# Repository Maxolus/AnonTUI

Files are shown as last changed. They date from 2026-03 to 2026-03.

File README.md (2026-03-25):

# MoTUI: Personalization of In-Vehicle Tactile Interfaces for People With Vision Impairments and the Blind

<p align="center">
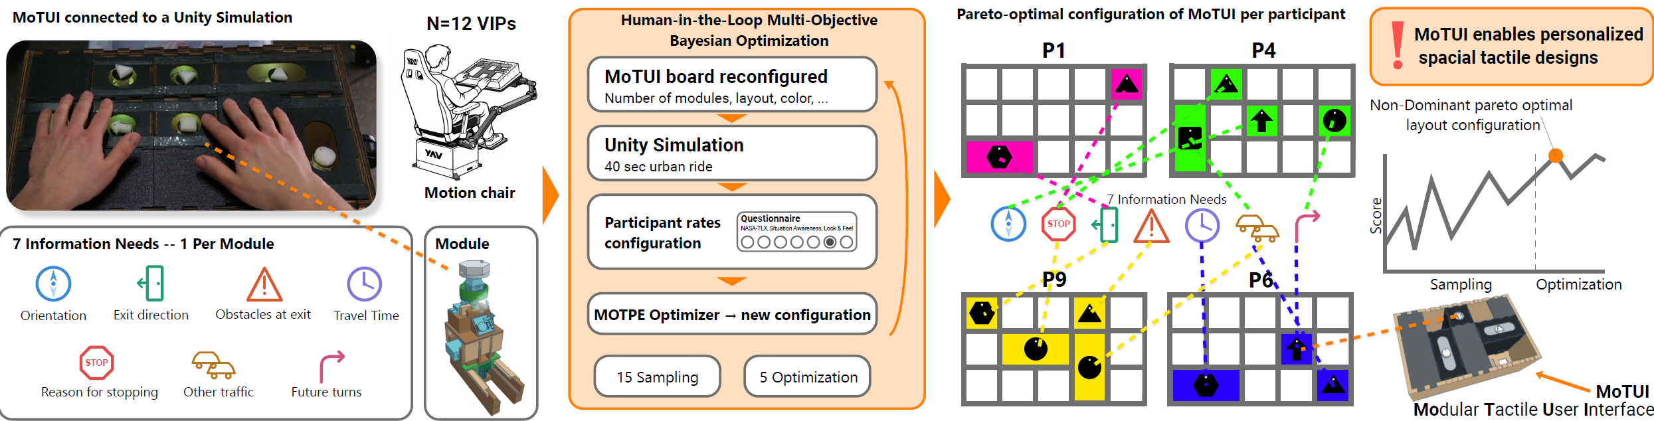
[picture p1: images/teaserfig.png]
MoTUI Teaser Figure
  
</p>

<p align="center">
  
  
  
  
  
  
  
  
  
</p>

---

## 📄 About

**MoTUI** is an open-source **Modular Tactile User Interface** that pairs reconfigurable hardware with **Human-in-the-Loop Multi-Objective Bayesian Optimization (HITL-MOBO)** to personalize in-vehicle interfaces for people with vision impairments (VIPs). Instead of one-size-fits-all designs, MoTUI lets each user arrive at their own Pareto-optimal configuration through iterative feedback.

> *"The last presentation of the 21 runs, that last demonstration, that was mine: the speech rate was right, the elements were perfectly tangible, and the cues like 'stop because of pedestrian' or 'oncoming car' and the mention of obstacles at the exit all fit. With that setup I could imagine getting into such a car and driving off alone."* — P9

## ✨ Key Results

In a within-subject study (**N=12 VIPs**), HITL-optimized configurations significantly outperformed both a static baseline and an LLM-generated design:

| Metric | Optimization | LLM Baseline | Static (OnBoard) | Sig. |
|---|---|---|---|---|
| **Situation Awareness** | M=0.85, SD=0.11 | M=0.57, SD=0.33 | M=0.74, SD=0.22 | ✅ Opt > LLM* |
| **RAW NASA-TLX** (↓ better) | M=0.14, SD=0.09 | M=0.36, SD=0.24 | M=0.23, SD=0.12 | ✅ Opt < LLM* |
| **Look & Feel** | M=0.82, SD=0.11 | M=0.57, SD=0.29 | M=0.71, SD=0.27 | ✅ Opt > LLM* |
| **Ownership** | M=5.83, SD=1.34 | M=4.17, SD=1.95 | M=4.58, SD=1.73 | ✅ Opt > LLM* & Static* |

> \* p < .05

Crucially, the optimization converged on **substantially different configurations** across participants — confirming that personalization is essential and cannot be replaced by group-level defaults.

## 🧩 System Overview

### Hardware
Each MoTUI module features:
- 🔘 **MX Button** with tactile response (Linear / Tactile / Clicky)
- 🔄 **360° Rotation** (1 DOF)
- ⬆️ **Vertical rising movement** (1 DOF)
- ↔️ **Horizontal slide** (1 DOF)
- 📳 **Vibration motor**
- 💡 **RGB LED**
- 🔲 **Interchangeable top elements** (Circle, Triangle, Square, Hexagon, Arrow)

Modules are housed in laser-cut wooden chassis (88×88mm or 88×176mm) and arranged on a **5×3 base plate** (47×30cm) offering up to **15 positions**. Connected to an **Arduino Mega 2560** via custom connectors with **6× PCA9685 PWM driver boards**.

### Seven Information Needs (1 per module)

| # | Information Need | Rotation | Vertical | Horizontal | Speech Example |
|---|---|---|---|---|---|
| 0 | 🧭 Orientation to destination | Points to destination | Extends at arrival | Reflects destination position | *"Your final destination is to the right behind you."* |
| 1 | 🚪 Exit direction | Points to exit | Extends at arrival | Shifts per exit side | *"Safe exit direction on the right."* |
| 2 | ⚠️ Obstacles at exit | Points to obstacle | Extends if obstacle | Reflects obstacle position | *"Caution: a tree to your right in front."* |
| 3 | ⏱️ Time to destination | Clock-like movement | Retracts at arrival | Progress bar | *"45 seconds left to reach destination."* |
| 4 | 🛑 Reason for stopping | Points to reason | Extends at stop | Progress bar for duration | *"Reason for stop: pedestrian crossing."* |
| 5 | 🚗 Other traffic | Points to traffic | Extends when near | Reflects position | *"Oncoming traffic on the left side."* |
| 6 | ↩️ Future turns | Points per turn | Extends if upcoming | Distance indicator | *"Upcoming left turn."* |

### Optimization Pipeline

```
┌─────────────────────────────────────────────────────┐
│  HITL-MOBO with MOTPE (Optuna 4.5.0)               │
│                                                     │
│  15 Sampling Trials  →  5 Optimization Trials       │
│  (fixed seed, all      (MOTPE refines based         │
│   modules appear ≥5×)   on participant ratings)     │
│                                                     │
│  Objectives:                                        │
│    ↑ Maximize Situation Awareness                   │
│    ↑ Maximize Look & Feel                           │
│    ↓ Minimize Perceived Workload (NASA-TLX)         │
│                                                     │
│  → Pareto-optimal non-dominant solution per user    │
└─────────────────────────────────────────────────────┘
```

### Parameter Space

**Global Parameters** (shared across modules):
- Color hue (HSV, S=V=100%)
- Button type (MX Black / Grey / Green)
- Vibration intensity, on-time, off-time
- Servo speed (100–300 deg/s)
- Speech output speed (100–250 WPM)

**Local Parameters** (per module, conditional on activation):
- x position (0–4), y position (0–2)
- Vertical movement, top element shape
- Use vibration, use rotation

## 🛠️ Repository Structure

```
MoTUI/
├── hardware/               # CAD files, circuit plans, manufacturing guide
│   ├── cad/                # 3D models for module chassis
│   ├── circuits/           # Arduino schematics & PCB designs
│   └── bom.csv             # Bill of materials
├── firmware/               # Arduino Mega 2560 firmware
├── unity/                  # Unity simulation environment (6000.0.53f1 LTS)
│   ├── Scenes/             # Urban HAV ride simulation
│   └── Scripts/            # Event triggers, module bridge
├── optimizer/              # Python HITL-MOBO pipeline
│   ├── motpe_optimizer.py  # Optuna MOTPE integration
│   ├── bridge.py           # Unity ↔ Arduino ↔ Optimizer communication
│   └── analysis/           # R scripts for statistical analysis
├── configs/                # Example Pareto-optimal configurations (N=12)
├── data/                   # Anonymized study data
└── README.md
```

## 🚀 Getting Started

### Prerequisites

- **Python 3.12+** with [Optuna](https://optuna.org/) 4.5.0
- **Unity 6000.0.53f1 LTS**
- **Arduino IDE** (for Mega 2560 firmware)
- **R 4.5.1** (for analysis scripts)

### Installation

```bash
# Clone the repository
git clone https://github.com/Maxolus/AnonTUI.git
cd AnonTUI

# Install Python dependencies
pip install -r requirements.txt

# Flash Arduino firmware
# (see hardware/README.md for wiring guide)

# Open Unity project
# (see unity/README.md for simulation setup)
```

### Running the Optimizer

```bash
python optimizer/motpe_optimizer.py \
  --n_sampling 15 \
  --n_optimization 5 \
  --seed 42
```

## 📊 Study Design

- **N=12** participants with low vision or legal blindness (M age = 56.75, SD = 15.47)
- **Within-subject**, counterbalanced across 3 conditions:
  1. **HITL-MOTPE Optimization** (20 trials: 15 sampling + 5 optimization)
  2. **OnBoard-inspired static baseline** ([Meinhardt et al., 2024](https://doi.org/10.1145/3659618))
  3. **LLM-generated configuration** (ChatGPT-5.2, single-shot from vision test data)
- **Simulation**: 40s urban HAV ride on **YawVR 2** motion chair with 75" 4K display
- **Measures**: Situation Awareness (SART), NASA-TLX, Look & Feel, Psychological Ownership

## 🔬 Contributions

- **Artifact Contribution**: MoTUI — an open-source tactile UI system and connected optimization framework for recreating and personalizing in-vehicle interface designs.
- **Empirical Study about People**: A within-subject study (N=12 VIPs) demonstrating how HITL-MOBO improves situation awareness, lowers mental workload, increases look & feel, and highlights the necessity of personalization over one-size-fits-all approaches.

## 📚 Citation

```bibtex
@inproceedings{anon2026motui,
  title     = {MoTUI: Personalization of In-Vehicle Tactile Interfaces 
               for People With Vision Impairments and the Blind},
  author    = {Anonymous Author(s)},
  booktitle = {Proceedings of the ACM Symposium on User Interface 
               Software and Technology (UIST '26)},
  year      = {2026},
  publisher = {ACM},
  doi       = {XXXXXXX.XXXXXXX}
}
```

## 🙏 Acknowledgments

We thank all 12 participants for their time, trust, and invaluable feedback during the study sessions.

## 📜 License

This project is open-sourced under the [MIT License](LICENSE).

---

<p align="center">
  <i>MoTUI enables personalized spatial tactile designs — because accessibility is not one-size-fits-all.</i>
</p>

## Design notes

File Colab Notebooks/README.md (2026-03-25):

# Layout Optimization Tool with Optuna

This project performs multi-objective optimization to determine the optimal layout of a modular board system, using [Optuna](https://optuna.org/). It evaluates various configurations of visual, haptic, and vibratory feedback modules in a constrained 5x3 board space.

---

## 💡 Features

- Multi-objective optimization (SART and NASA TLX)
- Layout visualization via `matplotlib`
- Board-space validation with pruning for invalid configurations
- Saves current trial configuration to JSON (for Unity integration)
- Logs all trials with parameters and scores to CSV and SQLite (`study.db`)

---

## 🧩 Modules & Parameters

- 7 modules (e.g., "Orientation at Destination", "Obstacles at Exit")
- Each module can have:
  - Size (Small / Large)
  - Position on a 5x3 board
  - Orientation (Vertical / Horizontal)
  - Color (RGB)
  - Elements Shape (Circle, Triangle, etc.)
  - Haptic Feedback Type (e.g., MX Black, MX Green)
  - Optional Vibration (Intensity, On/Off time)
  - Rotation (on/off)

---

## 🛠 How It Works

1. Loads or creates an Optuna study backed by SQLite (`study.db`).
2. For each trial:
   - Suggests the next module configuration based on Optuna's optimization algorithm (TPE sampler), taking into account previous trial results.
   - Prunes any overlapping or out-of-bounds configurations.
   - Plots the layout visually.
   - Prompts the user to enter **SART** and **NASA TLX** scores.
   - Saves results to:
     - `trial_log.csv`
     - `study.db`
     - `current_trial.json` (in Unity project's Assets folder)

---

## 🚀 Running the Script

### 🔧 Requirements

- Python 3.8+
- `optuna`
- `matplotlib`

Install dependencies:

```bash
pip install optuna matplotlib
```

### ▶️ Run

```bash
python your_script_name.py
```

Follow the on-screen instructions to evaluate each trial.

---

## 📁 Output Files

- `trial_log.csv` — all trials with parameters and scores.
- `current_trial.json` — configuration of the most recent trial (used by Unity).
- `study.db` — SQLite database storing all trial metadata.

---

## 📊 Visualization

Each layout is visualized with numbered rectangles showing position, size, and color of each module.

---

## ✏️ Evaluation Prompts

After each layout, the user is prompted to enter:

- **SART Score** (0–100)
- **NASA TLX Score** (0–100)

These scores are used as objectives for optimization.

---

## 📦 Integration

The saved JSON (`current_trial.json`) can be directly read by Unity for simulation or testing.

---

## 🧪 Number of Trials

By default, the script runs **10 evaluations**. Modify `NUM_EVALS` in the script to increase/decrease.

---

## ❗ Notes

- Prunes invalid configurations early for efficiency.
- Automatically resumes an existing study if one exists.
- Saves results incrementally after each trial.

---

## 📍 Author

Julian Zähnle  
Master Thesis Project

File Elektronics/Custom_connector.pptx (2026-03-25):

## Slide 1

18 Pin-Kabel (von der Elektronik-Box aus)

Arduino Pin

Arduino Pin

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
Rotation-Modul

Vibrationsmotor

Vertikal-Modul

Linear-Modul

Button

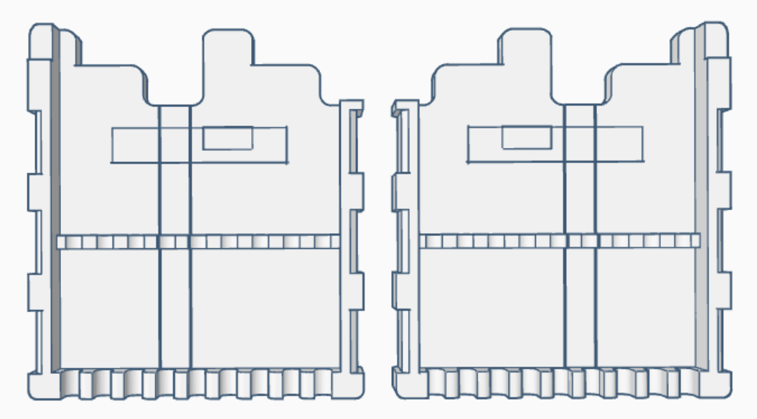
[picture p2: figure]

RGB-LED

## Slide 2

18 Pin-Kabel (von einem Modul aus)

Arduino Pin

Arduino Pin

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
Linear-Modul

RGB-LED

Vertikal-Modul

Button

Rotation-Modul

Vibrationsmotor

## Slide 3

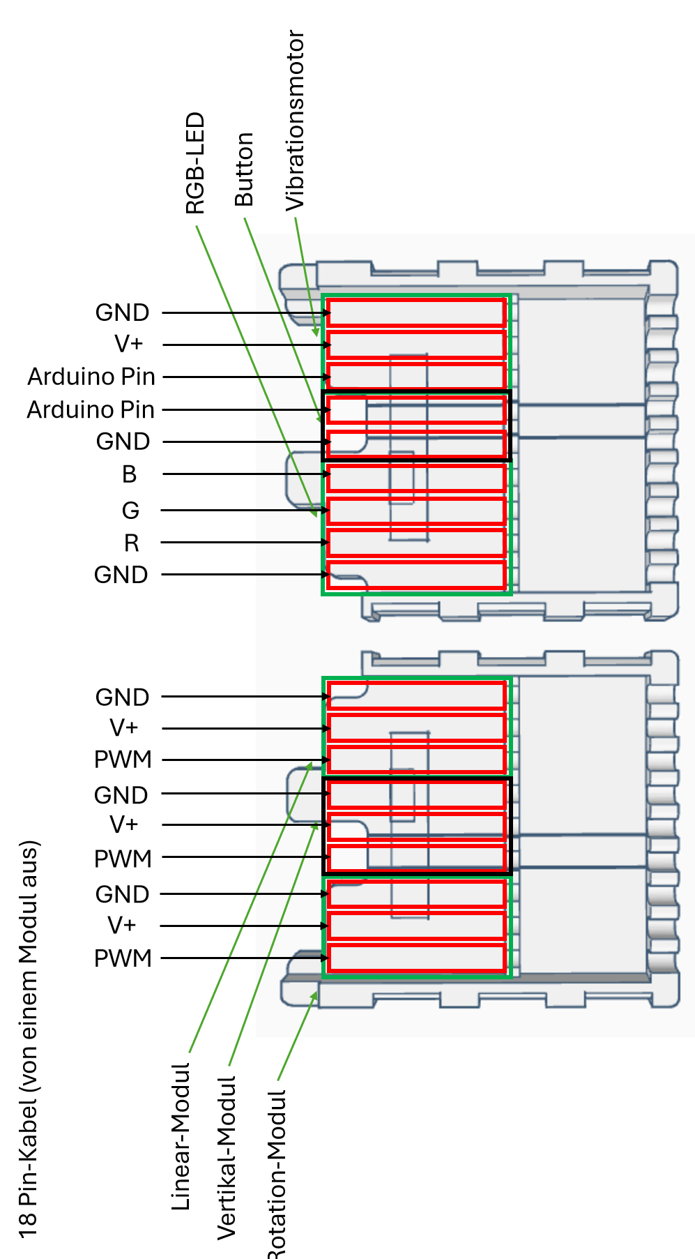
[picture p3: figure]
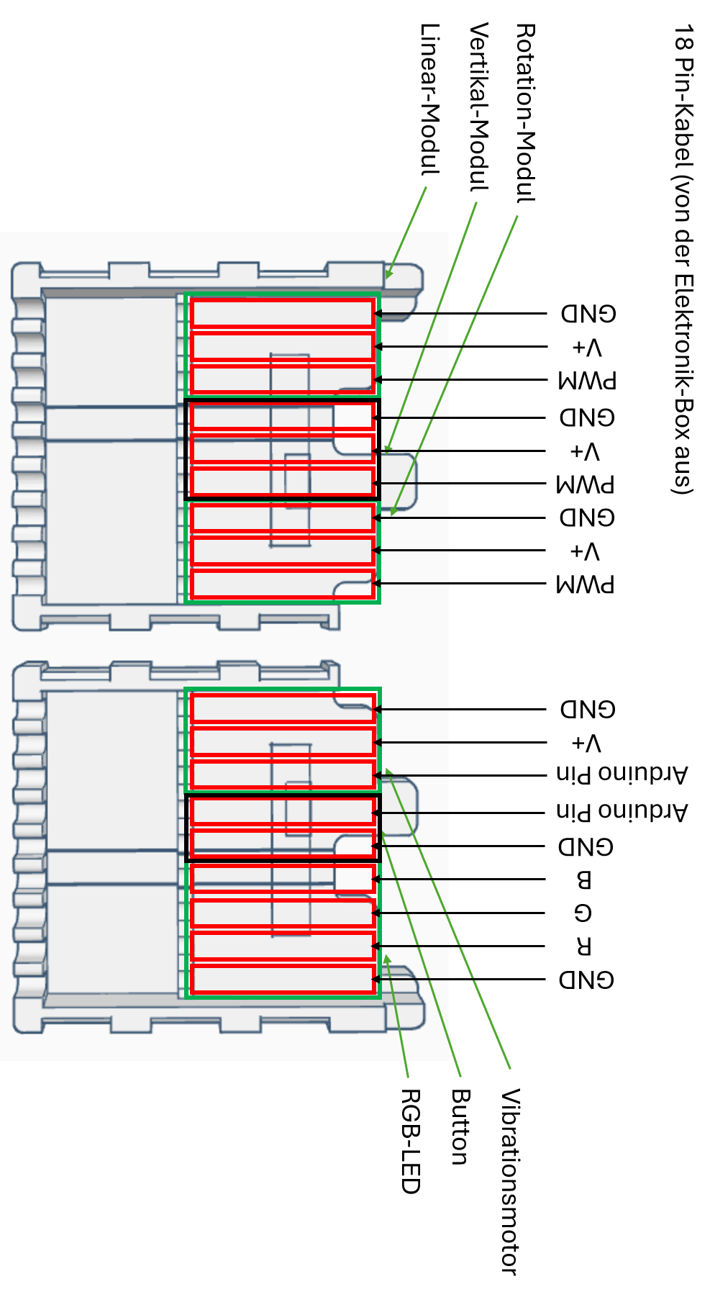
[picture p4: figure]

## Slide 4

15 Pin-Kabel (von der Elektronik-Box aus)

Arduino Pin

Arduino Pin

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
Rotation-Modul

Vertikal-Modul

Vibrationsmotor

Button

RGB-LED

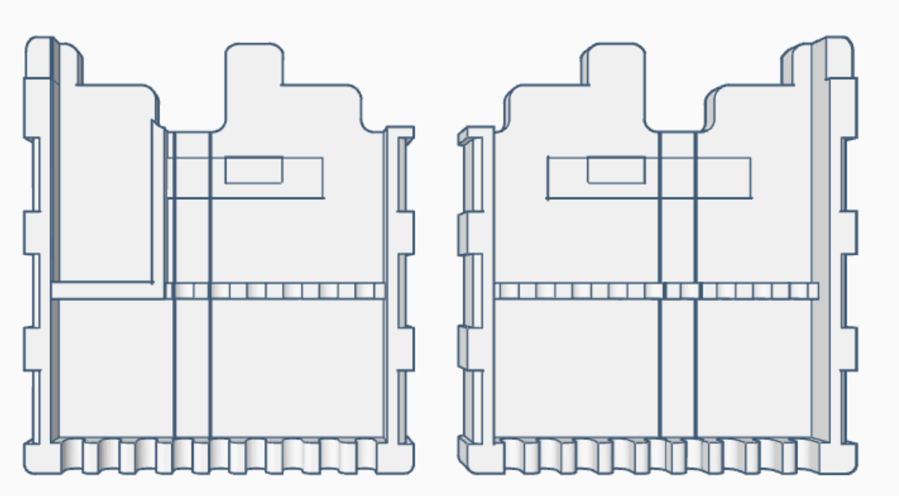
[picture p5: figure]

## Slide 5

15 Pin-Kabel (von einem Modul aus)

Arduino Pin

Arduino Pin

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
RGB-LED

Vertikal-Modul

Button

Rotation-Modul

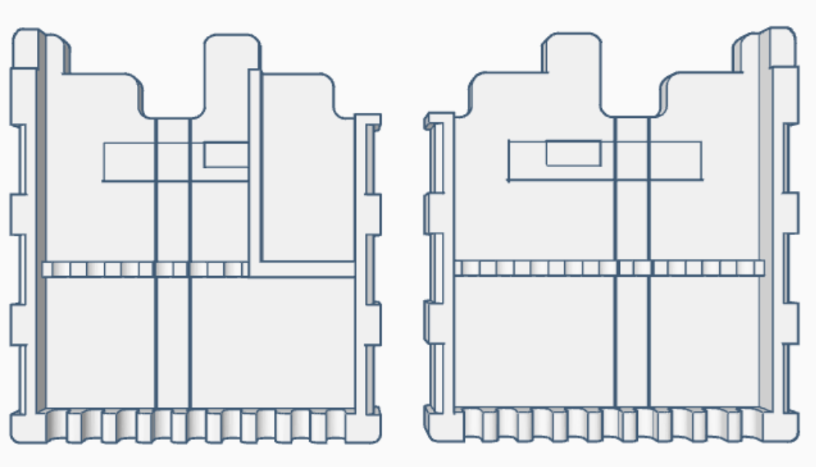
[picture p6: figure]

Vibrationsmotor

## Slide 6

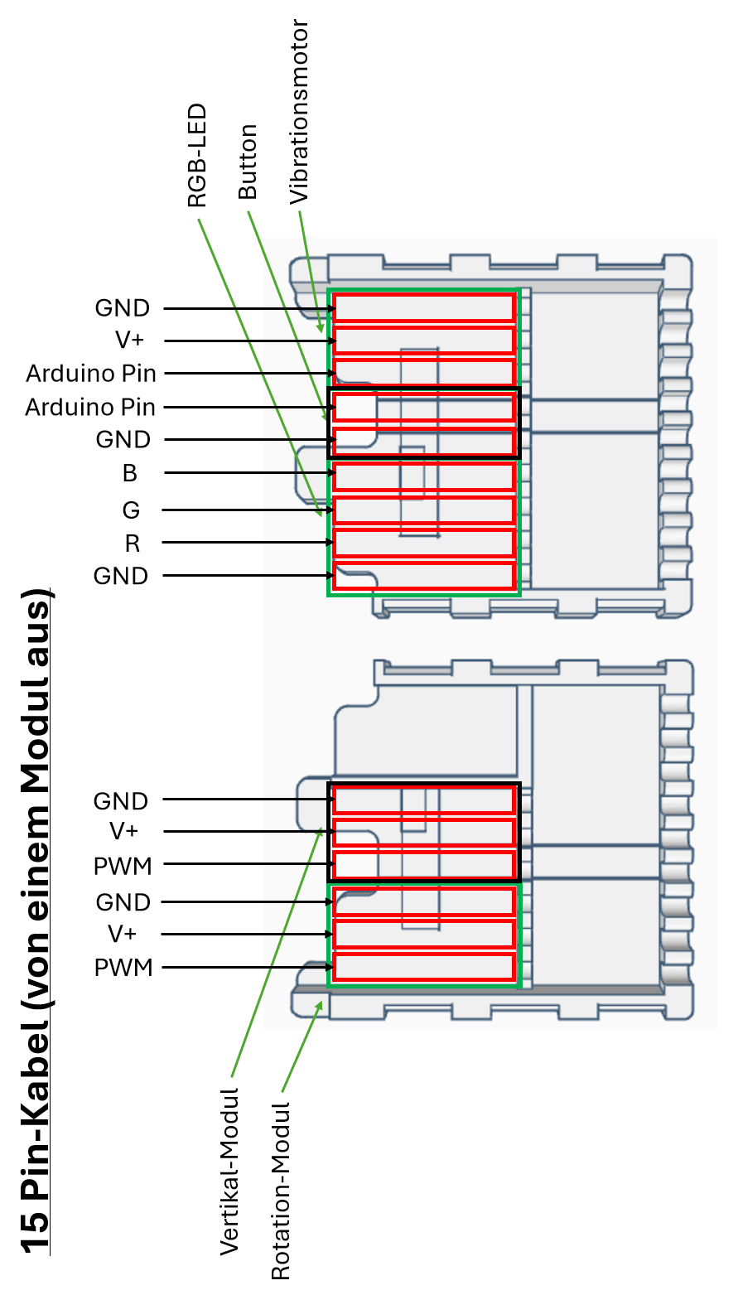
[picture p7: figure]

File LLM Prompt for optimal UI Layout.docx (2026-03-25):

This study is about a tactile user interface designed to help blind and visually impaired users achieve better situational awareness in an autonomous vehicle.

The tactile user interface can consist of up to seven modules. Each module is responsible for representing exactly one piece of information. Below is a list matching each module number to the specific information it represents:

0 = Orientation at destination

1 = Exit direction & Ground condition at Exit

2 = Obstacles at Exit

3 = distance/time and relationship to the destination

4 = reason for the vehicle stopping

5 = other traffic members

6 = future turn & Upcoming manuevers

These modules can be mounted on a board measuring 5 by 3 squares (x/y format). Information about the current situation is conveyed through linear, vertical, or rotational movements. Users can perceive this information by feeling the three-dimensional elements with different shapes attached to each module.

Each module can also vibrate when the corresponding situation changes. In addition, every module features a button that provides auditory feedback with additional information about the specific situation. The modules themselves are black, while the elements on the modules are colored.

Below is a list showing which information is represented by each module, along with the corresponding functions:

Number | Module | Rotation | Vibration | Vertical Extension | Linear Extension
0 | Orientation at Destination | Top element points into the direction of the final destination in regards to the AV and follows it | Module vibrates for 4 seconds when new information gets presented | Module extends when AV reaches the destination | Vertical Orientation: Linear position reflects the position of the final destination (the middle of linear extension is the position of the AV)"
1 | Exit direction & Ground condition at Exit | Top element points into the direction of the Exit direction | Module vibrates for 4 seconds when new information gets presented | Module extends when AV reaches the destination | Horizontal Orientation: Element moves left or right depending on the exit direction
2 | Obstacles at Exit | Top element points at the obstacle | Module vibrates for 4 seconds when new information gets presented | Module extends when AV reaches the destination & there is a obstacle at the destination | Vertical Orientation: Linear position reflects the position of the Obstacle (the middle of linear extension is the position of the AV)
3 | distance/time and relationship to the destination | Top element points into the direction of the final destination in regards to the AV and follows it | Module vibrates for 4 seconds when destination is reached | Module drives in when destination is reached | Horizontal Orientation: Linear movement acts as a progress bar for the estimated time until reaching the destination
4 | reason for the vehicle stopping | 1. Top element points into the direction of the the reason for the stop and follows him (e.g. for pedesstrian crossing) else it does nothing 2. Top element functions as a clock and gives estimated time for the stop | Module vibrates for 4 seconds when new information gets presented | Module extends when AV stops | Horizontal Orientation: Linear movement acts as a progress bar for the estimated stopping time
5 | other traffic members | Top element points into the direction of the traffic member and follows him | Module vibrates for 4 seconds when new information gets presented | Module extends when there are other traffic members close to the AV | Vertical Orientation: Postion reflects the position of the other traffic member (the middle of linear extension is the position of the AV)
6 | future turn & Upcoming manuevers | Top element points into the direction of the upcomming curve | Module vibrates for 4 seconds when new information gets presented | Module extends when there is an upcomming curve | Vertical Orientation: Distance between element and top boundary signals the distance to the upcomming curve

The parameters that can be modified are:

(local) Position of the modules on the board:
Tuple (x, y) [x: int 0–4 y: int 0–2]

(local) Used traffic information:
Boolean value [0, 1] [Orientation at destination, Exit direction & Ground condition at exit, Obstacles at exit, Distance/time and relation to the destination, Reason for the vehicle stopping, Other traffic participants, Future turns & Upcoming maneuvers]

(global) Color of the module elements:
Triple tuple (R, G, B) [RGB: int 0–255]

(local) Shape of the module elements:
Categorical object type SHAPES = ["Circle", "Triangle", "Square", "Hexagon", "Arrow"]

(global) Tactile feedback:
Type of tactile feedback for the button used on the elements → Discrete object type [int 0–2]
0 = No tactile feedback [MX Black Clear Top]
1 = Tactile feedback [MX Grey]
2 = Tactile and clicky feedback [MX Green]

(global) Servo speed:
Speed at which the elements on the modules move [int: 100°/s – 300°/s]

(global) Vibration intensity:
Intensity with which a module vibrates when conveying information [int: 65% – 100%]

(global) Vibration pattern:
Pattern used for module vibration:

- On-Time (PD): [int: 5 ms – 200 ms]
- Off-Time (IPI): [int: 10 ms – 500 ms]

(local) Functions used per module:

- use_rotation: [bool]
- use_vibration: [bool]
- use_horizontal_movement: [bool]

(global) Sound output speed:
Speed at which verbal information is delivered [int: 100 – 250 wpm]

Now, based on this description, decide on a configuration of these parameters that will provide the highest situational awareness, the lowest mental workload, and the best look and feel for the test subject described below.

Keep in mind that you will likely not be able to use all modules, since only one module can be placed on each field, and modules that use linear movement (use_horizontal_movement = large) require two adjacent fields.

You can also find below a list indicating whether a module (identified by its module number) requires one additional space in the x or y direction: (0 = y, 1 = x, 2 = y, 3 = x, 4 = x, 5 = y, 6 = y).

Test Subject (Description based on results from vision tests):

- Amsler Test:
  - The central dot is not visible
  - Presence of “holes” or gray veils
  - Dark or blurry areas
  - Squares appear in different sizes
  - Bent or distorted lines
- Ishihara Color Test:
  - Red-green color deficiency (Deuteranomaly/Protanomaly)
  - Color blindness (stronger form, Dichromasy)
- Snellen Chart Test:
  - 20/40 visual acuity
- Pelli-Robson Chart:
  - logCS = 1.65
- Completely blind.

Provide me with an assignment of these parameters in the following JSON format within their respective defined value ranges (only for the parameters that are also included in the example JSON file). Maintain the JSON format exactly ("extension_length": 8.5 is a fixed value)!

Note that the global parameters are the same for all modules. This means that the RGB colors, tactile feedback, servo speed, vibration intensity, vibration pattern, and sound output speed have the same values for all modules.

Provide all additional parameters that are not included in the JSON file as a separate list (not in JSON format): [Used Traffic Information | Position of the modules on the board | Shape of the module elements | Tactile feedback].

JSON Format:

{

"extension_length": 8.5,

"servo_speed": 200,

"sound_output_speed": 125,

"use_module_0": true,

"large_0": false,

"r_0": 208,

"g_0": 249,

"b_0": 118,

"use_vibration_0": false,

"vibration_intensity_0": 0,

"vibration_on_time_0": 0,

"vibration_off_time_0": 0,

"use_rotation_0": true,

"use_module_1": true,

"large_1": false,

"r_1": 236,

"g_1": 138,

"b_1": 210,

"use_vibration_1": true,

"vibration_intensity_1": 71,

"vibration_on_time_1": 110,

"vibration_off_time_1": 396,

"use_rotation_1": false,

"use_module_2": true,

"large_2": false,

"r_2": 30,

"g_2": 32,

"b_2": 211,

"use_vibration_2": false,

"vibration_intensity_2": 0,

"vibration_on_time_2": 0,

"vibration_off_time_2": 0,

"use_rotation_2": true,

"use_module_3": true,

"large_3": true,

"r_3": 147,

"g_3": 103,

"b_3": 104,

"use_vibration_3": false,

"vibration_intensity_3": 0,

"vibration_on_time_3": 0,

"vibration_off_time_3": 0,

"use_rotation_3": false,

"use_module_4": true,

"large_4": false,

"r_4": 37,

"g_4": 188,

"b_4": 82,

"use_vibration_4": false,

"vibration_intensity_4": 0,

"vibration_on_time_4": 0,

"vibration_off_time_4": 0,

"use_rotation_4": true,

"use_module_5": true,

"large_5": true,

"r_5": 160,

"g_5": 96,

"b_5": 121,

"use_vibration_5": false,

"vibration_intensity_5": 0,

"vibration_on_time_5": 0,

"vibration_off_time_5": 0,

"use_rotation_5": true,

"use_module_6": false,

"large_6": false,

"r_6": 0,

"g_6": 0,

"b_6": 0,

"use_vibration_6": false,

"vibration_intensity_6": 0,

"vibration_on_time_6": 0,

"vibration_off_time_6": 0,

"use_rotation_6": false

}

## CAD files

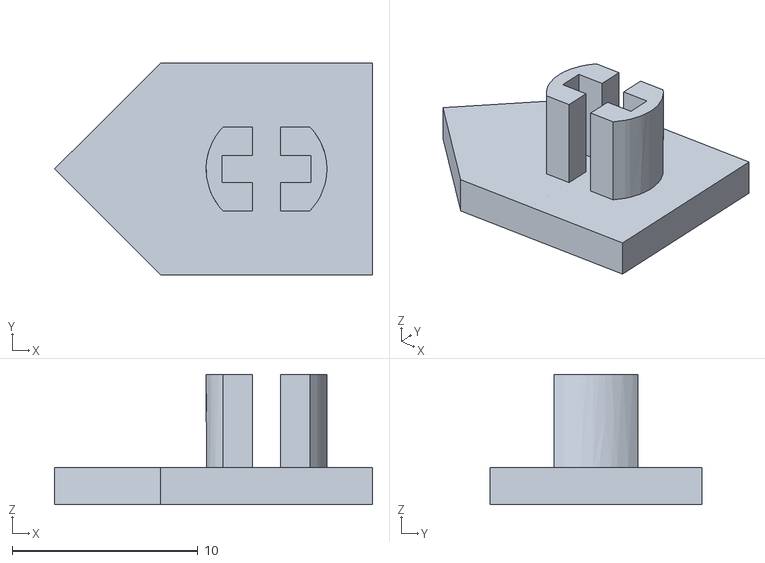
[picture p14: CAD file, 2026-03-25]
3D Printing - STL Files/Button/but top.stl
17.1 x 11.4 x 7.00

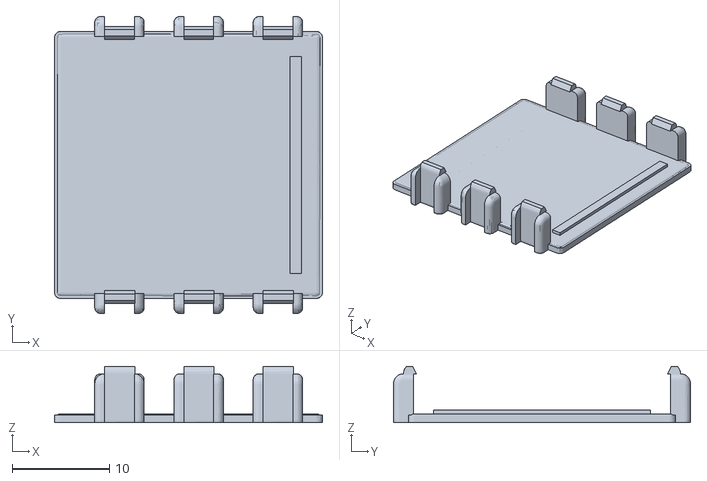
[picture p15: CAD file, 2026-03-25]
3D Printing - STL Files/Dupont Cable/Klemme.stl
27.6 x 30.6 x 5.79

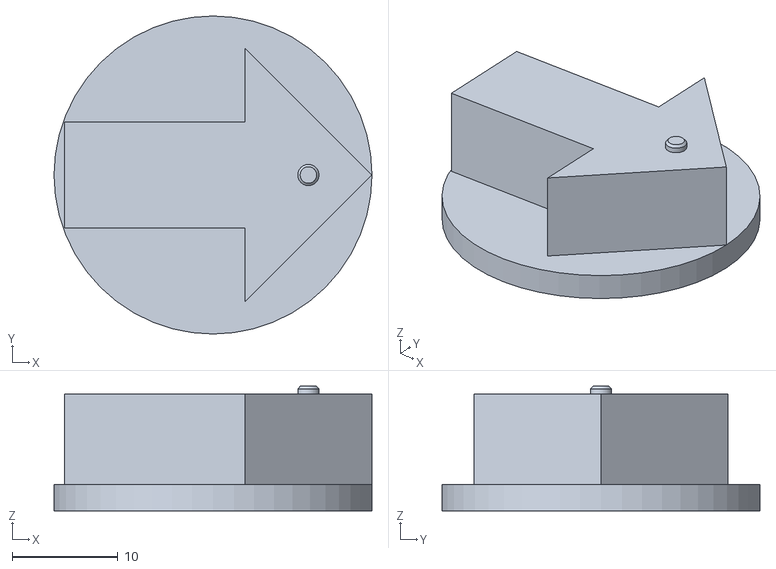
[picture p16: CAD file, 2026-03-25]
3D Printing - STL Files/LED Elemente/Arrow.stl
30.0 x 30.0 x 11.8

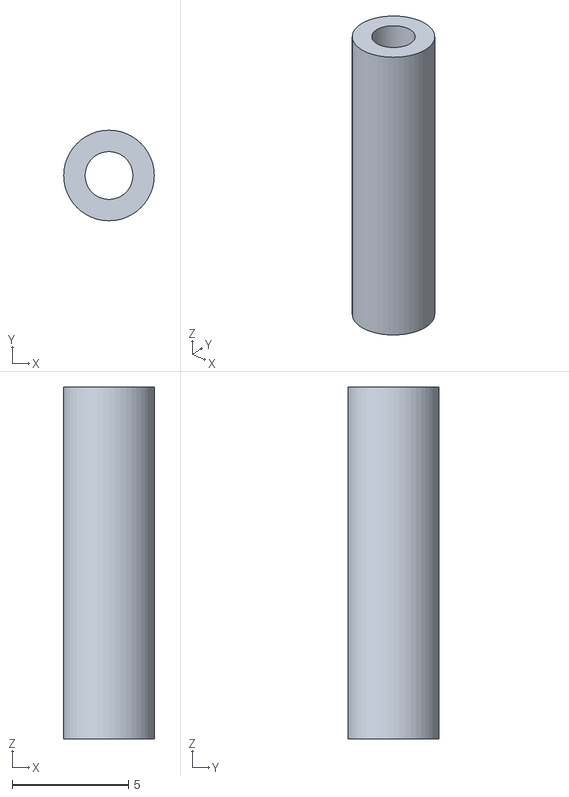
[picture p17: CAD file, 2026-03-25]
3D Printing - STL Files/Linear/linear Pipe.stl
3.90 x 3.90 x 15.1

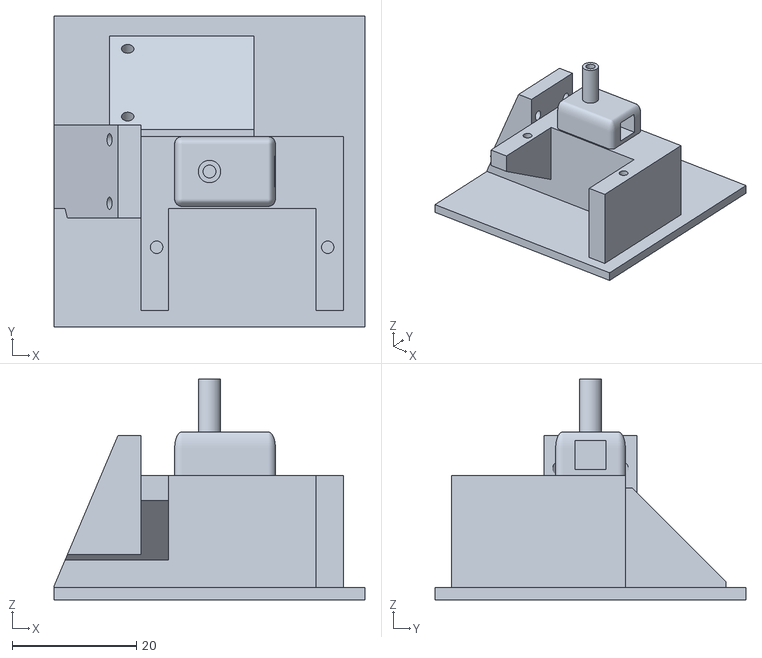
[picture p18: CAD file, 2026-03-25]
3D Printing - STL Files/Rotation/rotation Bottom.stl
50.0 x 50.0 x 35.5

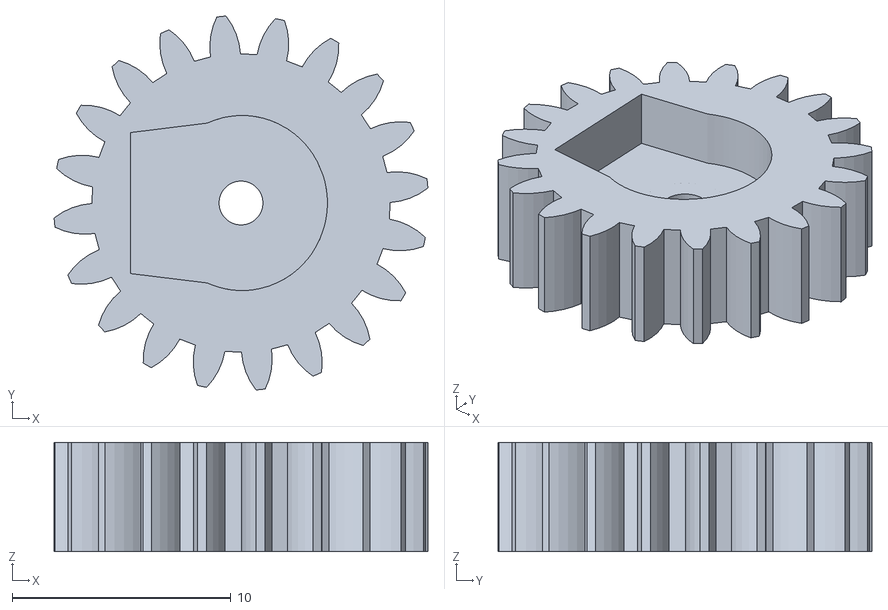
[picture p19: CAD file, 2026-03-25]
3D Printing - STL Files/Servo Gear.stl
17.1 x 17.1 x 5.00

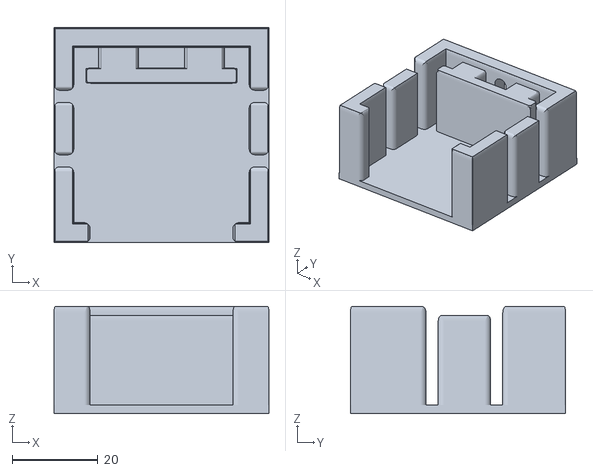
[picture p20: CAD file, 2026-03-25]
3D Printing - STL Files/Vertical/vertical Top.stl
50.0 x 50.0 x 25.0

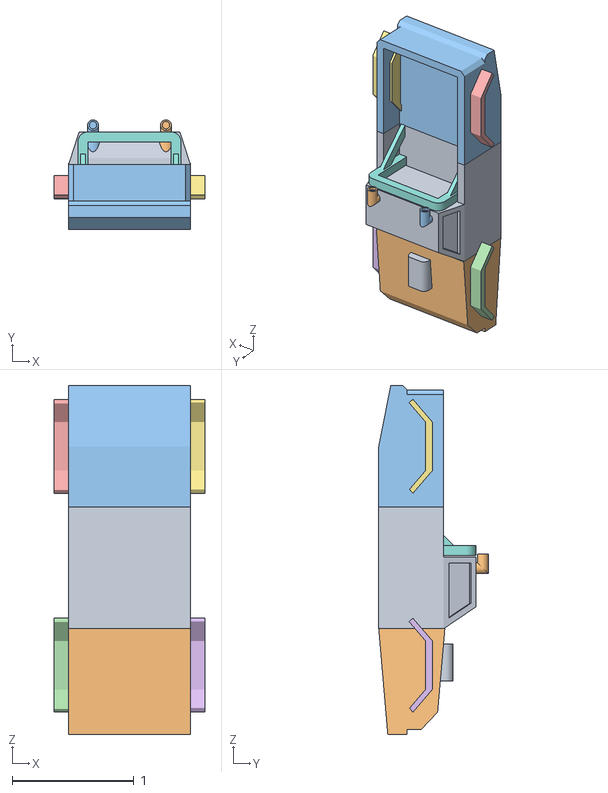
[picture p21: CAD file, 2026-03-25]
unity/MoTUI-Simulation/Assets/YawVR/Sample/Arcade_Car_Physics/Models/Car01.obj
1.24 x 0.901 x 2.87
windshield_truck_28
hood_default_29
trunk_bed_30
detail_fenderSquare_31
detail_fenderSquare_32
detail_fenderSquare_33
detail_fenderSquare_34
detail_rollbar_35
detail_engine_36
detail_exhaustVertical_38
detail_exhaustVertical_39

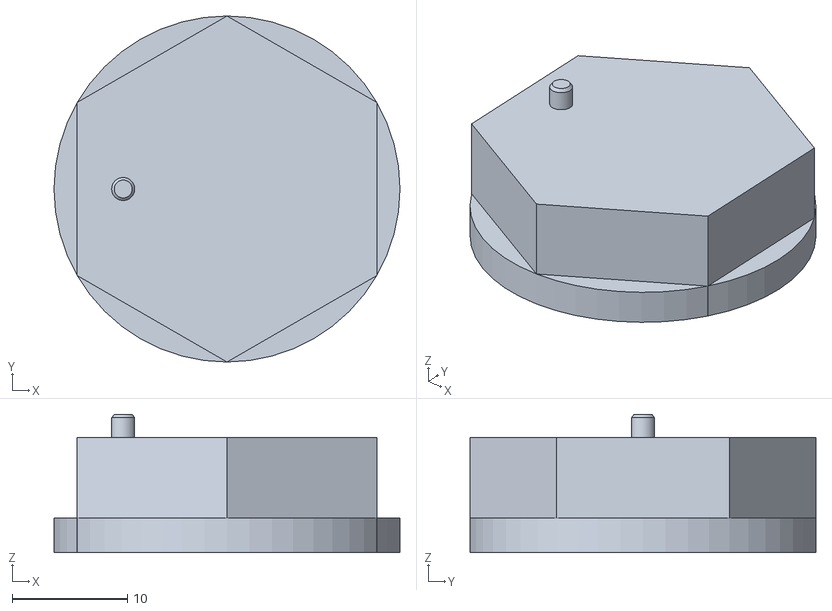
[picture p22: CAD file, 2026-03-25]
3D Printing - STL Files/Button/top piece test.stl
30.0 x 30.0 x 12.0

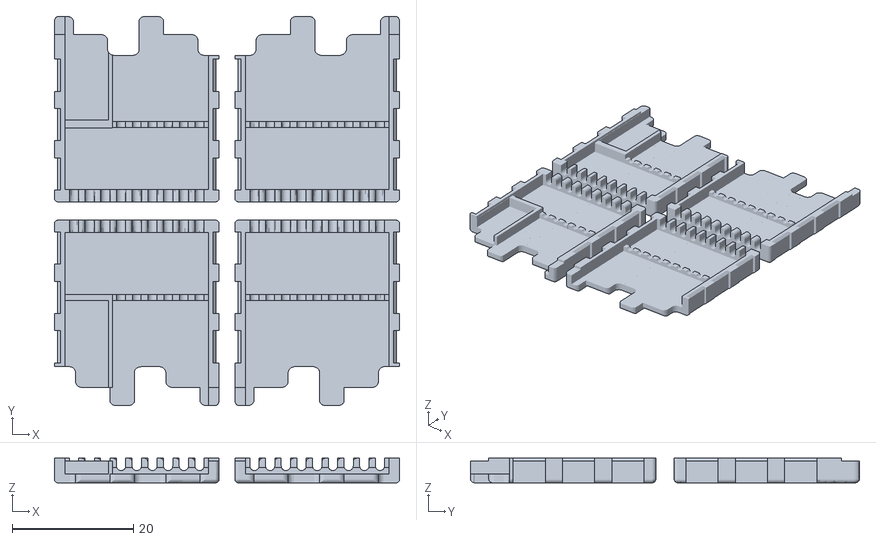
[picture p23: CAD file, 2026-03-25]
3D Printing - STL Files/Dupont Cable/15_Pin_Top.stl
57.0 x 64.2 x 4.08

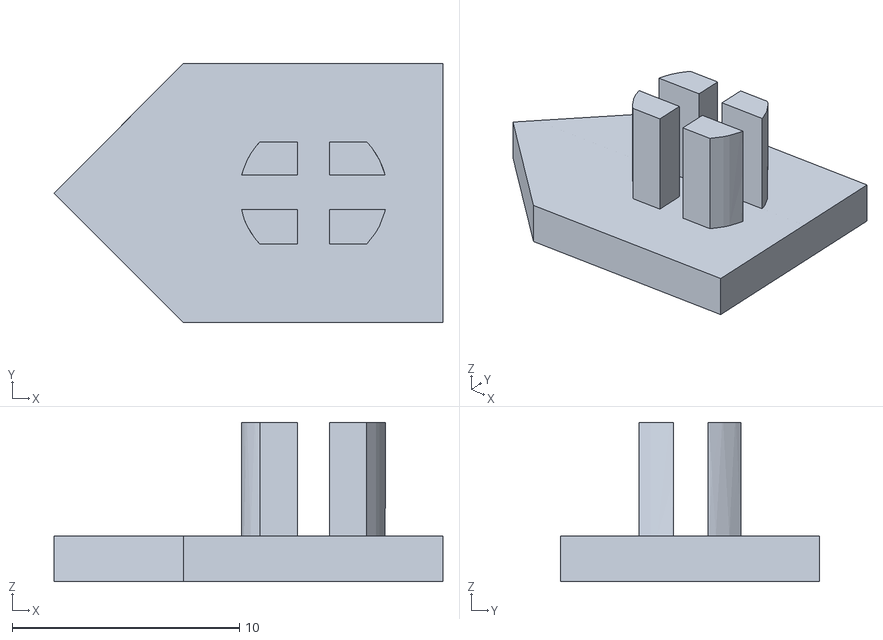
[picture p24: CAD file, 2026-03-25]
3D Printing - STL Files/LED Elemente/Button_Connector.stl
17.1 x 11.4 x 7.00

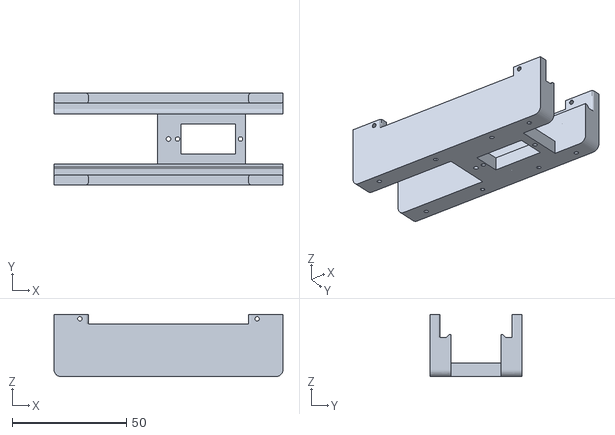
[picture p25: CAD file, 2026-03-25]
3D Printing - STL Files/Linear/linear Bottom.stl
100.0 x 40.0 x 27.1

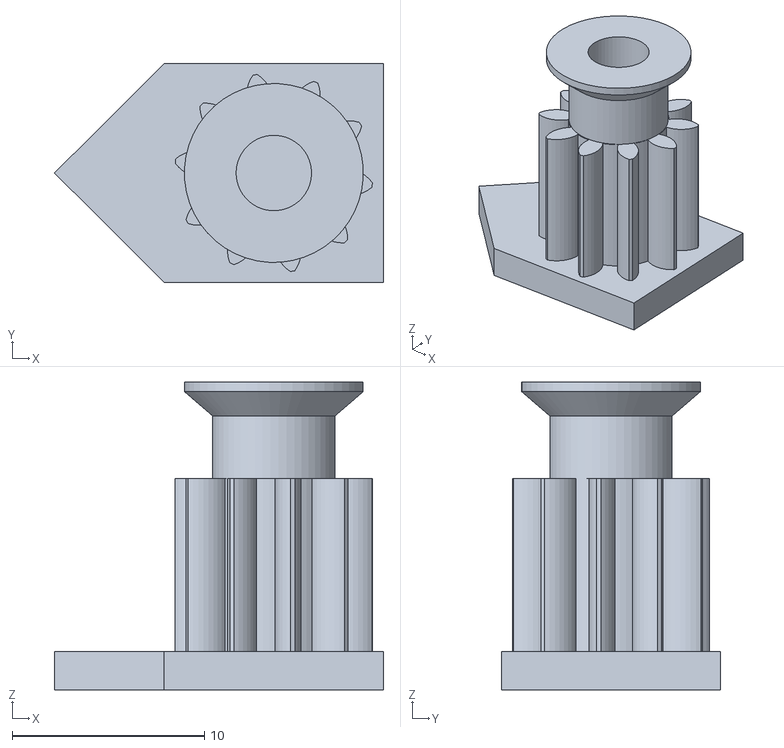
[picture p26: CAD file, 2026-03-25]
3D Printing - STL Files/Rotation/rotation Gear Small.stl
17.1 x 11.4 x 16.0

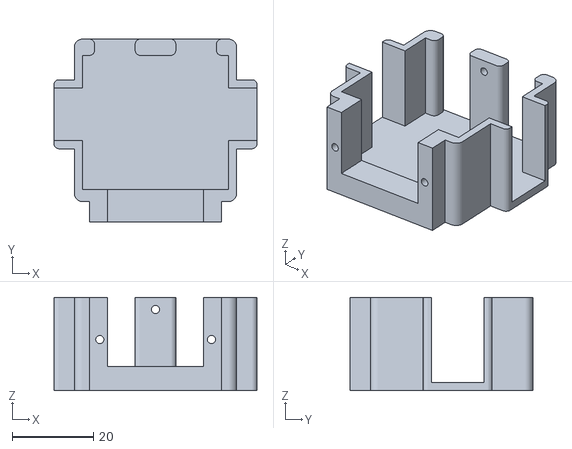
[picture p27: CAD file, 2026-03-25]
3D Printing - STL Files/Vertical/vertical Bottom.stl
50.0 x 45.0 x 23.0

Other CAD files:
unity/MoTUI-Simulation/Assets/YawVR/Sample/Arcade_Car_Physics/Models/Wheel01.obj
3D Printing - STL Files/Button/top texture test.stl
3D Printing - STL Files/Dupont Cable/18_Pin_Top.stl
3D Printing - STL Files/LED Elemente/Triangle.stl
3D Printing - STL Files/Button/but bottom.stl
3D Printing - STL Files/LED Elemente/Circle.stl
3D Printing - STL Files/LED Elemente/Hexagon.stl
3D Printing - STL Files/LED Elemente/Square.stl
3D Printing - STL Files/Linear/linear Gear Small.stl
3D Printing - STL Files/Linear/linear Guide.stl
3D Printing - STL Files/Linear/linear Straight Gear.stl
3D Printing - STL Files/Rotation/rotation Clip.stl
3D Printing - STL Files/Vertical/Cam Flat.stl

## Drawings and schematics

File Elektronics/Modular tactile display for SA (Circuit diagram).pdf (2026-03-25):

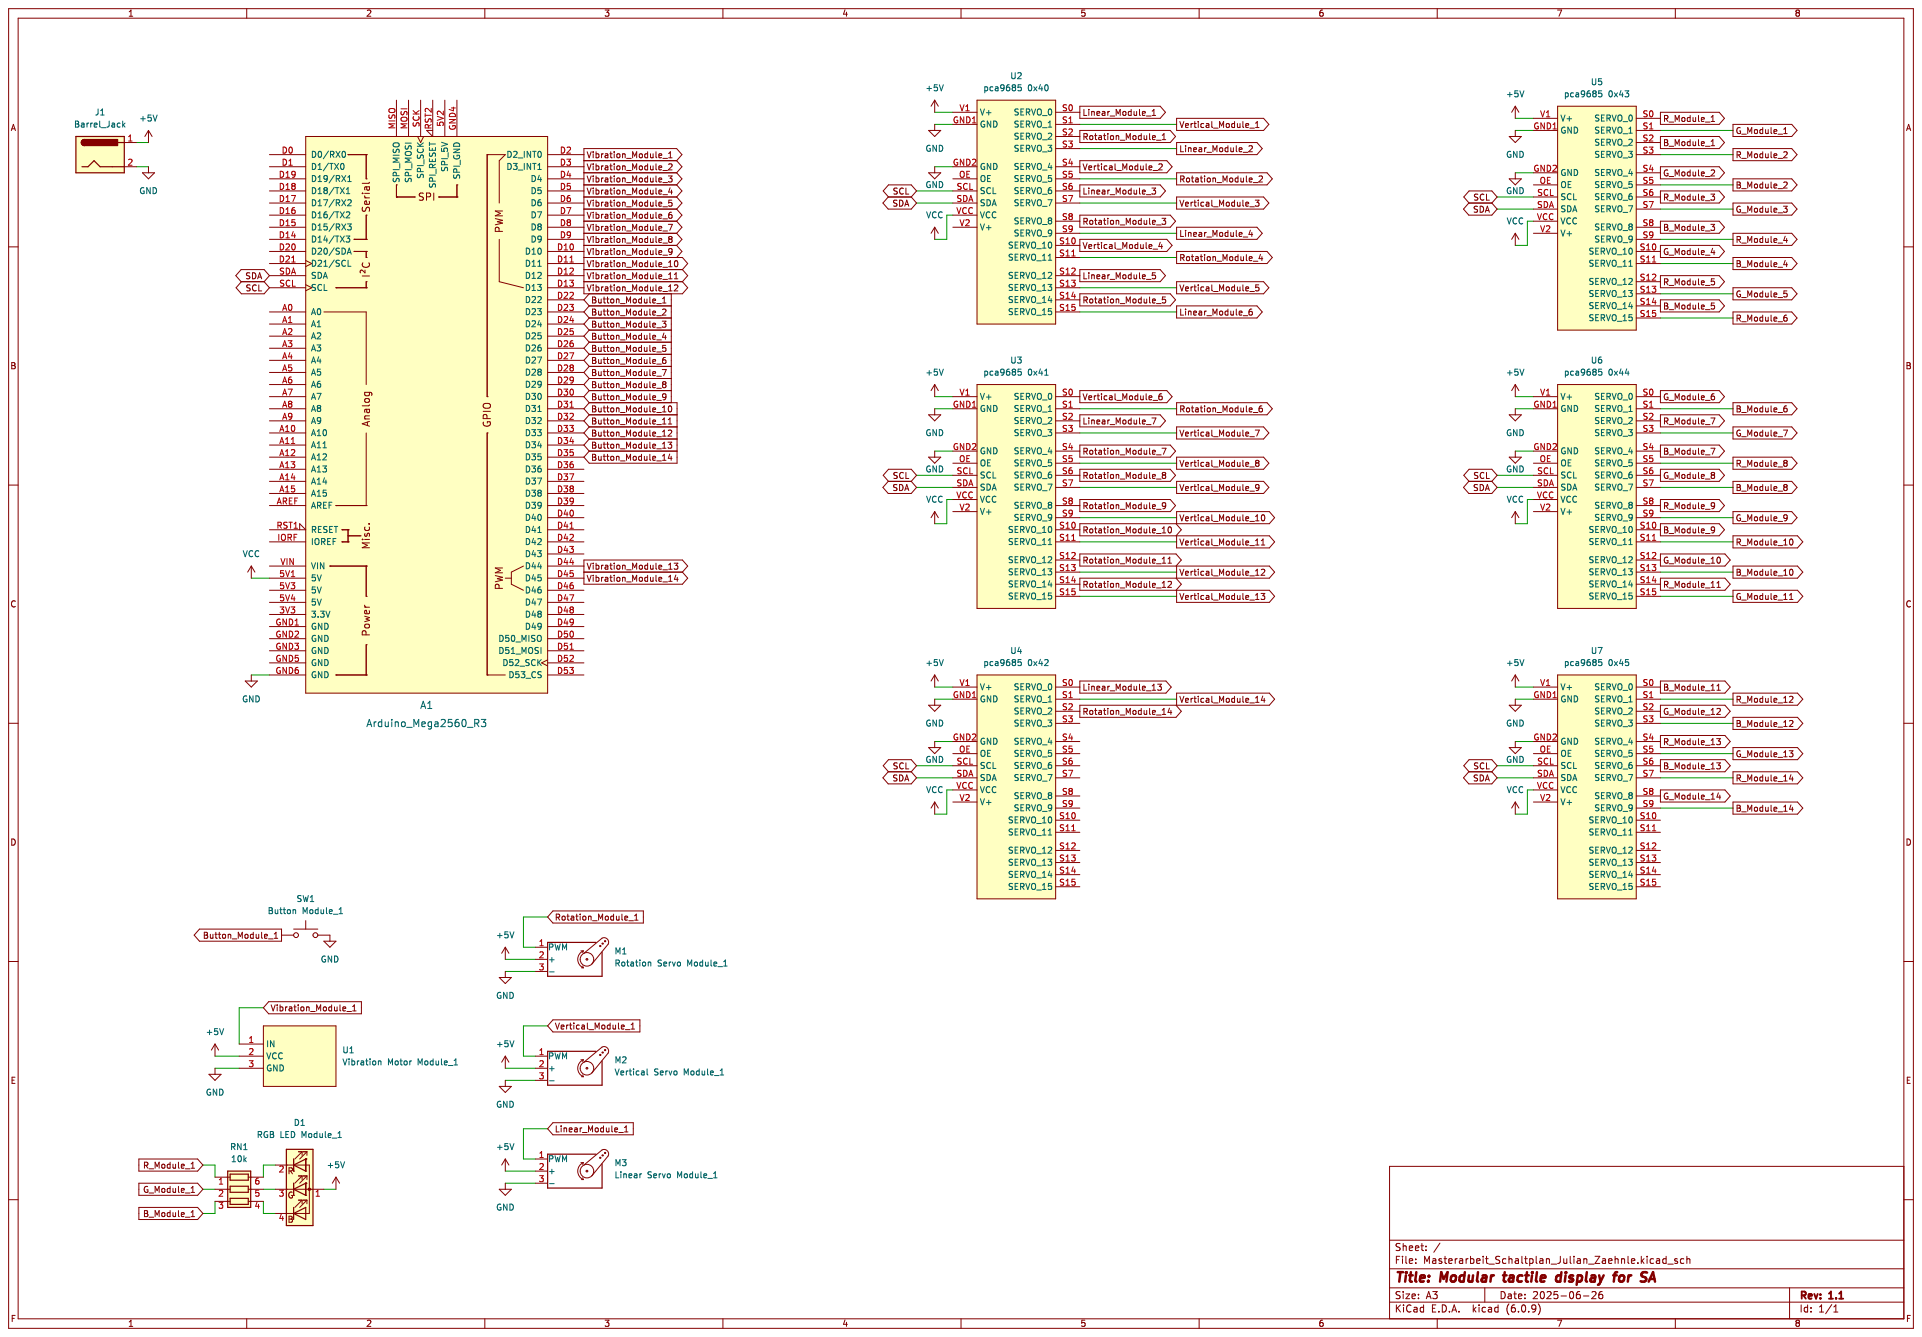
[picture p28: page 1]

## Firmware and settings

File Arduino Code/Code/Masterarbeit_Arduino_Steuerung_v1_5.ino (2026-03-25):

#include "VibMotorControl.h"
#include "ServoControl.h"
#include "buttons.h"
#include "ledcontrol.h"
#include "ModuleController.h"


void setup() {
  Serial.begin(115200);
  
  setupVibMotors();
  servoControlBegin();
  initButtons();

  setupLEDControllers();
  initializeLEDColors();  // Set colors from the array

  delay(1000);
}



void loop() {
  // Updates the vibration motors without blocking the loop
  updateVibMotors();
  // Updates the servo positions without blocking the loop
  servoControlUpdate();
  // Updates the button array without blocking the loop
  updateButtons();
  // Updates the LED array without blocking the loop
  initializeLEDColors();  // Set colors from the array


  // Communication-Code
  if (Serial.available()) {
    String line = Serial.readStringUntil('\n');
    processLine(line);
  }

  //delay(10); // Optional; adjust for performance
}

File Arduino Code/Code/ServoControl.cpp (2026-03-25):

#include "ServoControl.h"
#include <Wire.h>
#include <Adafruit_PWMServoDriver.h>

static const uint8_t controllerAddresses[NUM_CONTROLLERS] = {0x40, 0x41, 0x42};
static Adafruit_PWMServoDriver pwmControllers[NUM_CONTROLLERS] = {
  Adafruit_PWMServoDriver(0x40),
  Adafruit_PWMServoDriver(0x41),
  Adafruit_PWMServoDriver(0x42)
};

// PWM limits per servo
uint16_t pwmMin[NUM_SERVOS] = {
  110, 110, 110, 
  120, 110, 115, 
  120, 120, 110, 
  120, 110, 110, 
  110, 110, 125, 
  110, 110, 80,         // Module 6
  110, 110, 60, 
  110, 100, 
  110, 80, 
  110, 120,             // Module 10
  110, 90, 
  110, 70,              // Module 12
  110, 80, 
  110, 60
};

uint16_t pwmMax[NUM_SERVOS] = {
  525, 525, 560, 
  525, 530, 525, 
  525, 525, 555, 
  505, 525, 530, 
  525, 525, 525, 
  520, 520, 620,        // Module 6
  525, 510, 540, 
  525, 550, 
  520, 550, 
  525, 580,             // Module 10
  525, 585,             // Module 11
  500, 555, 
  525, 555, 
  525, 580
};

// Angle limits per servo
float angleMin[NUM_SERVOS] = {
  15, 10, 0, 
  15, 10, 0, 
  15, 10, 0, 
  15, 10, 0, 
  15, 10, 0, 
  15, 10, 0, 
  15, 10, 0, 
  10, 0,
  10, 0, 
  10, 0, 
  10, 0, 
  10, 0, 
  10, 0, 
  10, 0
};

float angleMax[NUM_SERVOS] = {
  165, 90, 180, 
  165, 90, 180, 
  165, 90, 180, 
  165, 90, 180, 
  165, 90, 180, 
  165, 90, 180, 
  165, 90, 180, 
  90, 180, 
  90, 180, 
  90, 180, 
  90, 180, 
  90, 180, 
  90, 180, 
  90, 180
};

// Start angle per servo
float servoTargetAngle[NUM_SERVOS] = {
  90, 0, 90,              //0,1,2
  90, 0, 90,              //3,4,5
  90, 0, 90,              //6,7,8
  90, 0, 90,              //9,10,11
  90, 0, 90,              //12,13,14
  90, 0, 90,              //15,16,17
  90, 0, 90,              //18,19,20
  0, 90,                  //21,22
  0, 90,                  //23,24            
  0, 90,                  //25,26 
  0, 90,                  //27,28 
  0, 90,                  //29,30 
  0, 90,                  //31,32 
  0, 90                   //33,34
};


float servoStartAngle[NUM_SERVOS] = {
  90, 0, 90, 
  90, 0, 90, 
  90, 0, 90, 
  90, 0, 90, 
  90, 0, 90, 
  90, 0, 90, 
  90, 0, 90, 
  0, 90, 
  0, 90, 
  0, 90, 
  0, 90, 
  0, 90, 
  0, 90, 
  0, 90
};

static float servoCurrentAngle[NUM_SERVOS];

float speedDegPerSec = 200.0;      //min: 60 / max: 600
static unsigned long lastUpdate = 0;
static const unsigned long updateInterval = 20; // ms

static void writeServo(uint8_t index, uint16_t pwmValue);
static uint16_t angleToPWM(uint8_t index, float angle);



void servoControlBegin() {
  Wire.begin();

  for (uint8_t i = 0; i < NUM_CONTROLLERS; i++) {
    pwmControllers[i].begin();
    pwmControllers[i].setPWMFreq(50); // 50Hz for Servos
  }

  for (uint8_t i = 0; i < NUM_SERVOS; i++) {
    servoCurrentAngle[i] = servoStartAngle[i]; // start at this angle
    writeServo(i, angleToPWM(i, servoCurrentAngle[i])); // set initial value directly
  }

  delay(500); // short pause for initialization

  // Move all servos to target position
  lastUpdate = millis();
  while (true) {
    servoControlUpdate();
    bool allReached = true;
    for (uint8_t i = 0; i < NUM_SERVOS; i++) {
      if (abs(servoCurrentAngle[i] - servoTargetAngle[i]) > 1.0) {
        allReached = false;
        break;
      }
    }
    if (allReached) break;
    delay(updateInterval);
  }
}


void servoControlUpdate() {
  unsigned long now = millis();
  if (now - lastUpdate < updateInterval) return;

  float dt = (now - lastUpdate) / 1000.0f;
  lastUpdate = now;

  float maxStep = speedDegPerSec * dt;

  for (uint8_t i = 0; i < NUM_SERVOS; i++) {
    float diff = servoTargetAngle[i] - servoCurrentAngle[i];
    if (abs(diff) > maxStep) {
      servoCurrentAngle[i] += (diff > 0 ? maxStep : -maxStep);
    } else {
      servoCurrentAngle[i] = servoTargetAngle[i];
    }
    writeServo(i, angleToPWM(i, servoCurrentAngle[i]));
  }
}


void servoControlSetTargetAngle(uint8_t index, float angle) {
  if (index >= NUM_SERVOS) return;
  servoTargetAngle[index] = constrain(angle, angleMin[index], angleMax[index]);
}




static void writeServo(uint8_t index, uint16_t pwmValue) {
  uint8_t controllerIndex = index / 16;
  uint8_t channel = index % 16;
  pwmControllers[controllerIndex].setPWM(channel, 0, pwmValue);
}


static uint16_t angleToPWM(uint8_t index, float angle) {
  angle = constrain(angle, angleMin[index], angleMax[index]);
  float ratio = (angle - 0) / (180 - 0);      //float ratio = (angle - angleMin[index]) / (angleMax[index] - angleMin[index]);
  return pwmMin[index] + ratio * (pwmMax[index] - pwmMin[index]);
}

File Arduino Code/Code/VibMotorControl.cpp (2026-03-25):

#include "VibMotorControl.h"

const uint8_t vibMotorPins[NUM_VIBMOTORS] = {
  2, 3, 4, 5, 6, 7, 8,
  9, 10, 11, 12, 46, 44, 45
};

bool vibMotorActive[NUM_VIBMOTORS] = {
  0, 0, 0, 0, 0, 0, 0,
  0, 0, 0, 0, 0, 0, 0
};

unsigned long vibMotorOnTime[NUM_VIBMOTORS] = {
  500, 500, 500, 500, 500, 500, 500,
  500, 500, 500, 500, 500, 500, 500
};

unsigned long vibMotorOffTime[NUM_VIBMOTORS] = {
  500, 500, 500, 500, 500, 500, 500,
  500, 500, 500, 500, 500, 500, 500
};

uint8_t vibMotorIntensityPercent[NUM_VIBMOTORS] = {
  100, 100, 100, 100, 100, 100, 100,                       
  100, 100, 100, 100, 100, 100, 100
};

// Internal state (only needed in this file)
static bool vibMotorIsOn[NUM_VIBMOTORS] = { false };
static unsigned long vibMotorLastToggleTime[NUM_VIBMOTORS] = { 0 };

void setupVibMotors() {
  for (uint8_t i = 0; i < NUM_VIBMOTORS; i++) {
    pinMode(vibMotorPins[i], OUTPUT);
    analogWrite(vibMotorPins[i], 0);
    vibMotorIsOn[i] = false;
    vibMotorLastToggleTime[i] = millis();
  }
}

void updateVibMotors() {
  unsigned long currentMillis = millis();

  for (uint8_t i = 0; i < NUM_VIBMOTORS; i++) {
    if (!vibMotorActive[i]) {
      analogWrite(vibMotorPins[i], 0);
      vibMotorIsOn[i] = false;
      continue;
    }

    if (vibMotorIsOn[i]) {
      if (currentMillis - vibMotorLastToggleTime[i] >= vibMotorOnTime[i]) {
        analogWrite(vibMotorPins[i], 0);
        vibMotorIsOn[i] = false;
        vibMotorLastToggleTime[i] = currentMillis;
      }
    } else {
      if (currentMillis - vibMotorLastToggleTime[i] >= vibMotorOffTime[i]) {
        uint8_t intensityPWM = map(vibMotorIntensityPercent[i], 0, 100, 0, 255);
        analogWrite(vibMotorPins[i], intensityPWM);
        vibMotorIsOn[i] = true;
        vibMotorLastToggleTime[i] = currentMillis;
      }
    }
  }
}

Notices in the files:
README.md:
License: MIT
